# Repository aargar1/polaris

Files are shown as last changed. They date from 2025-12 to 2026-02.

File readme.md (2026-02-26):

# Polaris
Polaris is a feature-rich development board built around the Lattice iCE40 FPGA, designed for experimentation and small FPGA-based projects. The board provides a practical set of peripherals for graphics, storage, and USB-based interaction, all in a compact and approachable design. I designed it to implement a custom 32-bit microcontroller.



## Features

- Lattice iCE40 FPGA
- VGA output with audio support
- SD card interface
- 2× USB Type-A ports
- User-controllable LED
- GPIO and SPI headers

## Tooling

Polaris is plug-and-play compatable with the `yosys` toolchain. The [iCEStudio](https://icestudio.io/) development enviornment provides a great ecosystem for development on Polaris and iCE40-based boards in general.

## Acknowlegments

Thanks to the open-source FPGA and KiCad communities, whose tools and documentation made this project possible.

## BOM (Hack Club Blueprint)
| Comment | Designator | Footprint | LCSC Part # | Direct Link |
| --- | --- | --- | --- | --- |
| 2150 | R11,R3,R7 | 0603 | C2960889 | [https://www.lcsc.com/product-detail/C2960889.html](https://www.lcsc.com/product-detail/C2960889.html) |
| 2.7nF | C15,C16 | 0603 | C1609 | [https://www.lcsc.com/product-detail/C1609.html](https://www.lcsc.com/product-detail/C1609.html) |
| Bus | J4 | 2x14 2.54mm | C725886 | [https://www.lcsc.com/product-detail/C725886.html](https://www.lcsc.com/product-detail/C725886.html) |
| VGA | J1 | ICD15S13E4GV00LF | C3121412 | [https://www.lcsc.com/product-detail/C3121412.html](https://www.lcsc.com/product-detail/C3121412.html) |
| 74CBTLV3126PW,118 | U2 | TSSOP-14 | C478017 | [https://www.lcsc.com/product-detail/C478017.html](https://www.lcsc.com/product-detail/C478017.html) |
| 47k | R17,R19–R24,R27,R30,R31 | 0603 | C25819 | [https://www.lcsc.com/product-detail/C25819.html](https://www.lcsc.com/product-detail/C25819.html) |
| WM8524CGEDT | U3 | TSSOP-16 | C146242 | [https://www.lcsc.com/product-detail/C146242.html](https://www.lcsc.com/product-detail/C146242.html) |
| 1Ω | R28,R29 | 0603 | C22936 | [https://www.lcsc.com/product-detail/C22936.html](https://www.lcsc.com/product-detail/C22936.html) |
| NRS4018T2R2MDGJ | L1 | SRN4018 | C92959 | [https://www.lcsc.com/product-detail/C92959.html](https://www.lcsc.com/product-detail/C92959.html) |
| W25Q16JVSNIQ | U4 | SOIC-8 | C115407 | [https://www.lcsc.com/product-detail/C115407.html](https://www.lcsc.com/product-detail/C115407.html) |
| 330Ω | R35,R36,R37 | 0603 | C23138 | [https://www.lcsc.com/product-detail/C23138.html](https://www.lcsc.com/product-detail/C23138.html) |
| TLV62568DBVR | U7 | SOT-23-5 | C163219 | [https://www.lcsc.com/product-detail/C163219.html](https://www.lcsc.com/product-detail/C163219.html) |
| 100nF | C1,C2,C3,C4,C5,C10,C14,C27,C30  | 0603 | C14663 | [https://www.lcsc.com/product-detail/C14663.html](https://www.lcsc.com/product-detail/C14663.html) |
| SW_Push | SW1 | 6mm | C455112 | [https://www.lcsc.com/product-detail/C455112.html](https://www.lcsc.com/product-detail/C455112.html) |
| 1.5k | R32,R33 | 0603 | C22843 | [https://www.lcsc.com/product-detail/C22843.html](https://www.lcsc.com/product-detail/C22843.html) |
| USB_A | J5,J6 | XKB U231-091N | C2880618 | [https://www.lcsc.com/product-detail/C2880618.html](https://www.lcsc.com/product-detail/C2880618.html) |
| 4.7uF | C6,C7,C8,C9,C17,C18,C19 | 0603 | C19666 | [https://www.lcsc.com/product-detail/C19666.html](https://www.lcsc.com/product-detail/C19666.html) |
| ICE40UP5K-SG48I | U1 | QFN-48 | C2678152 | [https://www.lcsc.com/product-detail/C2678152.html](https://www.lcsc.com/product-detail/C2678152.html) |
| Flashenable | JP1 | 1x02 2.54mm | C5360898 | [https://www.lcsc.com/product-detail/C5360898.html](https://www.lcsc.com/product-detail/C5360898.html) |
| LED_BGKR | D1 | 5mm RGB | C7117555 | [https://www.lcsc.com/product-detail/C7117555.html](https://www.lcsc.com/product-detail/C7117555.html) |
| 820Ω | R13,R14 | 0603 | C23253 | [https://www.lcsc.com/product-detail/C23253.html](https://www.lcsc.com/product-detail/C23253.html) |
| 10uF | C23,C24,C25,C26,C28,C29,C31,C32 | 0805 | C15850 | [https://www.lcsc.com/product-detail/C15850.html](https://www.lcsc.com/product-detail/C15850.html) |
| 560Ω | R25,R26 | 0603 | C23204 | [https://www.lcsc.com/product-detail/C23204.html](https://www.lcsc.com/product-detail/C23204.html) |
| 536Ω | R1,R5,R9 | 0603 | C23201 | [https://www.lcsc.com/product-detail/C23201.html](https://www.lcsc.com/product-detail/C23201.html) |
| SX5M25.000M20F30TNN | X1 | 25MHz Osc | C2901535 | [https://www.lcsc.com/product-detail/C2901535.html](https://www.lcsc.com/product-detail/C2901535.html) |
| MIC5504-3.3YM5 | U8 | SOT-23-5 | C41348078 | [https://www.lcsc.com/product-detail/C41348078.html](https://www.lcsc.com/product-detail/C41348078.html) |
| Prog | J2 | 1x08 2.54mm | C5156616 | [https://www.lcsc.com/product-detail/C5156616.html](https://www.lcsc.com/product-detail/C5156616.html) |
| FerriteBead_Small | FB1,FB2 | 0603 | C1027 | [https://www.lcsc.com/product-detail/C1027.html](https://www.lcsc.com/product-detail/C1027.html) |
| 4300Ω | R12,R4,R8 | 0603 | C23159 | [https://www.lcsc.com/product-detail/C23159.html](https://www.lcsc.com/product-detail/C23159.html) |
| 1uF | C12,C13 | 0603 | C15849 | [https://www.lcsc.com/product-detail/C15849.html](https://www.lcsc.com/product-detail/C15849.html) |
| 2.2uF | C11 | 0603 | C23630 | [https://www.lcsc.com/product-detail/C23630.html](https://www.lcsc.com/product-detail/C23630.html) |
| 10k | R15,R16,R18,R34 | 0603 | C25804 | [https://www.lcsc.com/product-detail/C25804.html](https://www.lcsc.com/product-detail/C25804.html) |
| 1070Ω | R10,R2,R6 | 0603 | C177957 | [https://www.lcsc.com/product-detail/C177957.html](https://www.lcsc.com/product-detail/C177957.html) |
| Barrel_Jack | J7 | PJ-063AH | C22434582 | [https://www.lcsc.com/product-detail/C22434582.html](https://www.lcsc.com/product-detail/C22434582.html) |
| SD_Card | J3 | 693063010911 | C341097 | [https://www.lcsc.com/product-detail/C341097.html](https://www.lcsc.com/product-detail/C341097.html) |
| SN74AHC00PWR | U9 | TSSOP-14 | C8143 | [https://www.lcsc.com/product-detail/C8143.html](https://www.lcsc.com/product-detail/C8143.html) |

## License
This project is licensed under the CERN Open Hardware Licence Version 2. If you would like to use Assemblage for a patently non-commercial or educational application, but cannot do so under this license, please contact me via an issue; I would be happy to work something out.

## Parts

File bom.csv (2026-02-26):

Comment | Designator | Footprint | LCSC Part #
2150 | R11,R3,R7 | 0603 | C2960889
2.7nF | C15,C16 | 0603 | C1609
Bus | J4 | PinHeader_2x14_P2.54mm_Vertical | C725886
VGA | J1 | ICD15S13E4GV00LF | C3121412
74CBTLV3126PW | 118 | U2 | TSSOP-14_4.4x5mm_P0.65mm | C478017
47k | R17,R19,R20,R21,R22,R23,R24,R27,R30,R31 | 0603 | C25819
WM8524CGEDT | U3 | TSSOP-16_4.4x5mm_P0.65mm | C146242
1 | R28,R29 | 0603 | C22936
NRS4018T2R2MDGJ | L1 | L_Bourns-SRN4018 | C92959
W25Q16JVSNIQ | U4 | SOIC-8_3.9x4.9mm_P1.27mm | C115407
330 | R35,R36,R37 | 0603 | C23138
TLV62568DBVR | U7 | SOT-23-5 | C163219
100nF | C1,C10,C14,C2,C27,C3,C30,C4,C5 | 0603 | C14663
SW_Push | SW1 | SW_PUSH_6mm | C455112
1.5k | R32,R33 | 0603 | C22843
USB_A | J5,J6 | USB_A_Receptacle_XKB_U231-091N-4BLRA00-S | C2880618
4.7uF | C17,C18,C19,C6,C7,C8,C9 | 0603 | C19666
ICE40UP5K-SG48I | U1 | QFN-48-1EP_7x7mm_P0.5mm_EP5.3x5.3mm | C2678152
Flashenable | JP1 | PinHeader_1x02_P2.54mm_Vertical | C5360898
LED_BGKR | D1 | LED_D5.0mm-4_RGB_Wide_Pins | C7117555
820 | R13,R14 | 0603 | C23253
10uF | C23,C24,C25,C26,C28,C29,C31,C32 | 0805 | C15850
560 | R25,R26 | 0603 | C23204
536 | R1,R5,R9 | 0603 | C23201
SX5M25.000M20F30TNN | X1 | Oscillator_SMD_SeikoEpson_SG8002LB-4Pin_5.0x3.2mm | C2901535
MIC5504-3.3YM5 | U8 | SOT-23-5 | C41348078
Prog | J2 | PinHeader_1x08_P2.54mm_Vertical | C5156616
FerriteBead_Small | FB1,FB2 | 0603 | C1027
4300 | R12,R4,R8 | 0603 | C23159
1u | C12,C13 | 0603 | C15849
2.2uF | C11 | 0603 | C23630
10k | R15,R16,R18,R34 | 0603 | C25804
1070 | R10,R2,R6 | 0603 | C177957
Barrel_Jack | J7 | BarrelJack_CUI_PJ-063AH_Horizontal | C22434582
SD_Card | J3 | 693063010911 | C341097
SN74AHC00PWR | U9 | TSSOP-14_4.4x5mm_P0.65mm | C8143

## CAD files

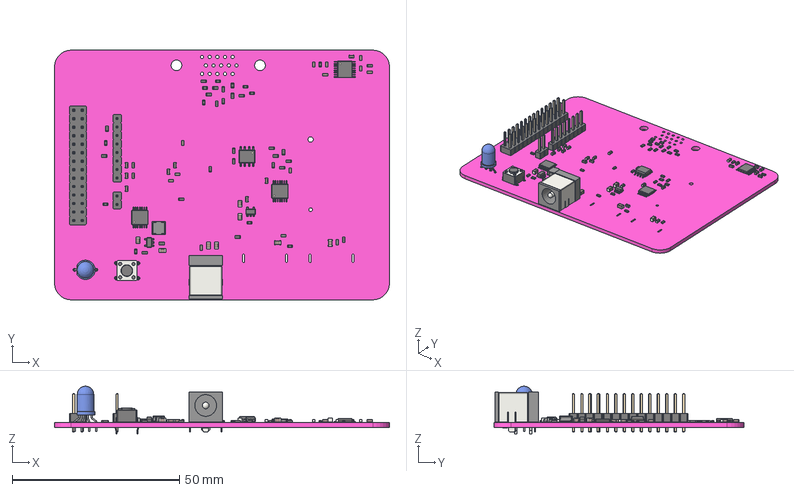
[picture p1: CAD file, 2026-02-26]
Polaris.step
100.2 x 74.8 x 14.3 mm
R_0603_1608Metric x 37
C_0805_2012Metric x 8
TSSOP-14_4.4x5mm_P0.65mm x 2
C_0603_1608Metric x 21
SOIC-8_3.9x4.9mm_P1.27mm
L_0603_1608Metric x 2
PinHeader_1x08_P2.54mm_Vertical
SOT-23-5 x 2
L_Bourns-SRN4018
PinHeader_2x14_P2.54mm_Vertical
PinHeader_1x02_P2.54mm_Vertical
BarrelJack_CUI_PJ-063AH_Horizontal
SW_PUSH_6mm
LED_D5.0mm-4_RGB_Wide_Pins
TSSOP-16_4.4x5mm_P0.65mm
Polaris_PCB

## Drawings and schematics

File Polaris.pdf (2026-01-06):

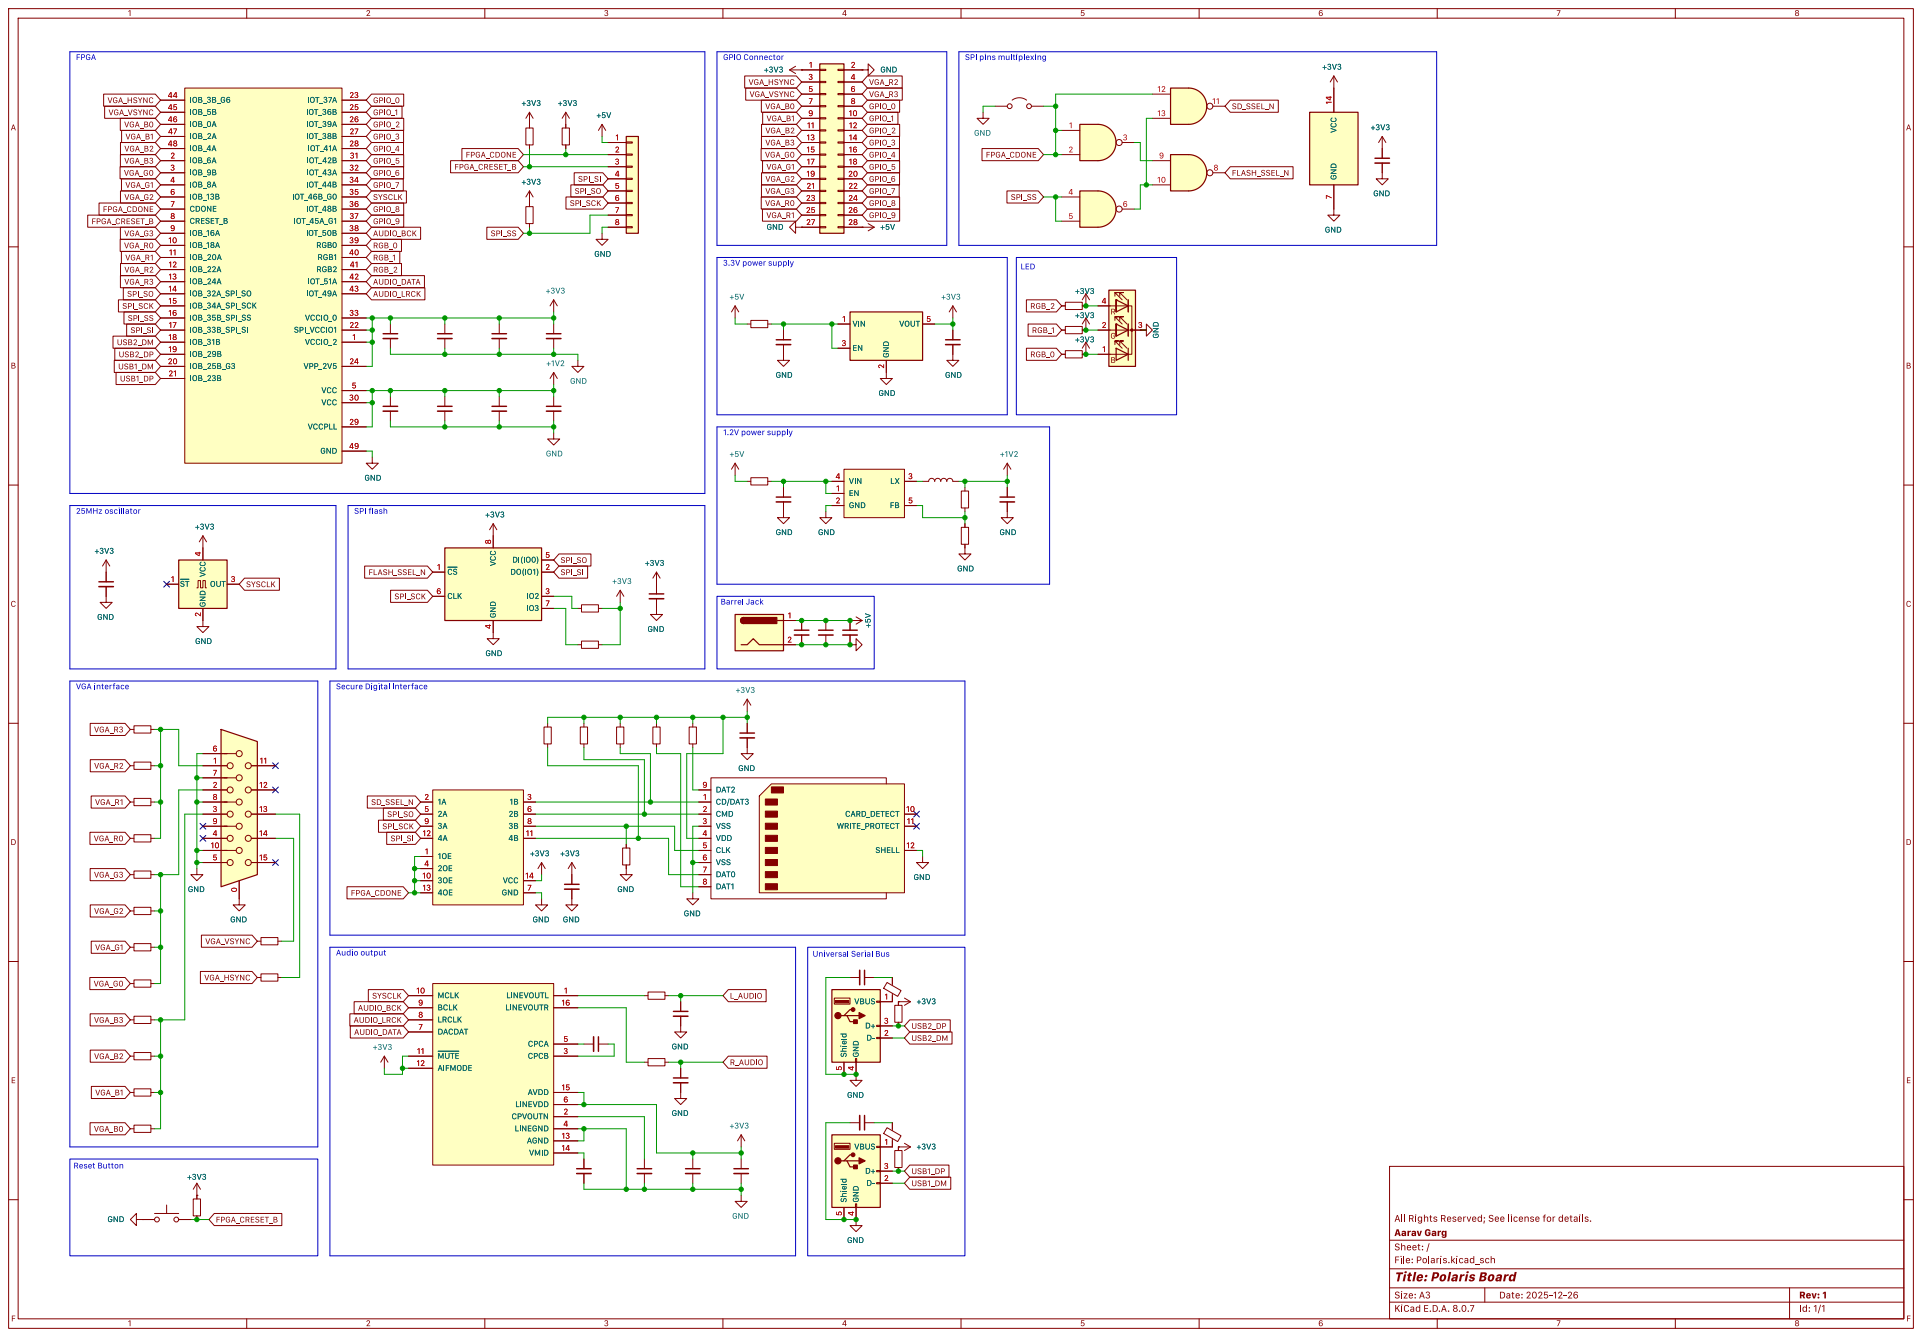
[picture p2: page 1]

File: Polaris.kicad_sch Sheet: / Aarav Garg All Rights Reserved; See license for details.

Id: 1/1 Title: Polaris Board

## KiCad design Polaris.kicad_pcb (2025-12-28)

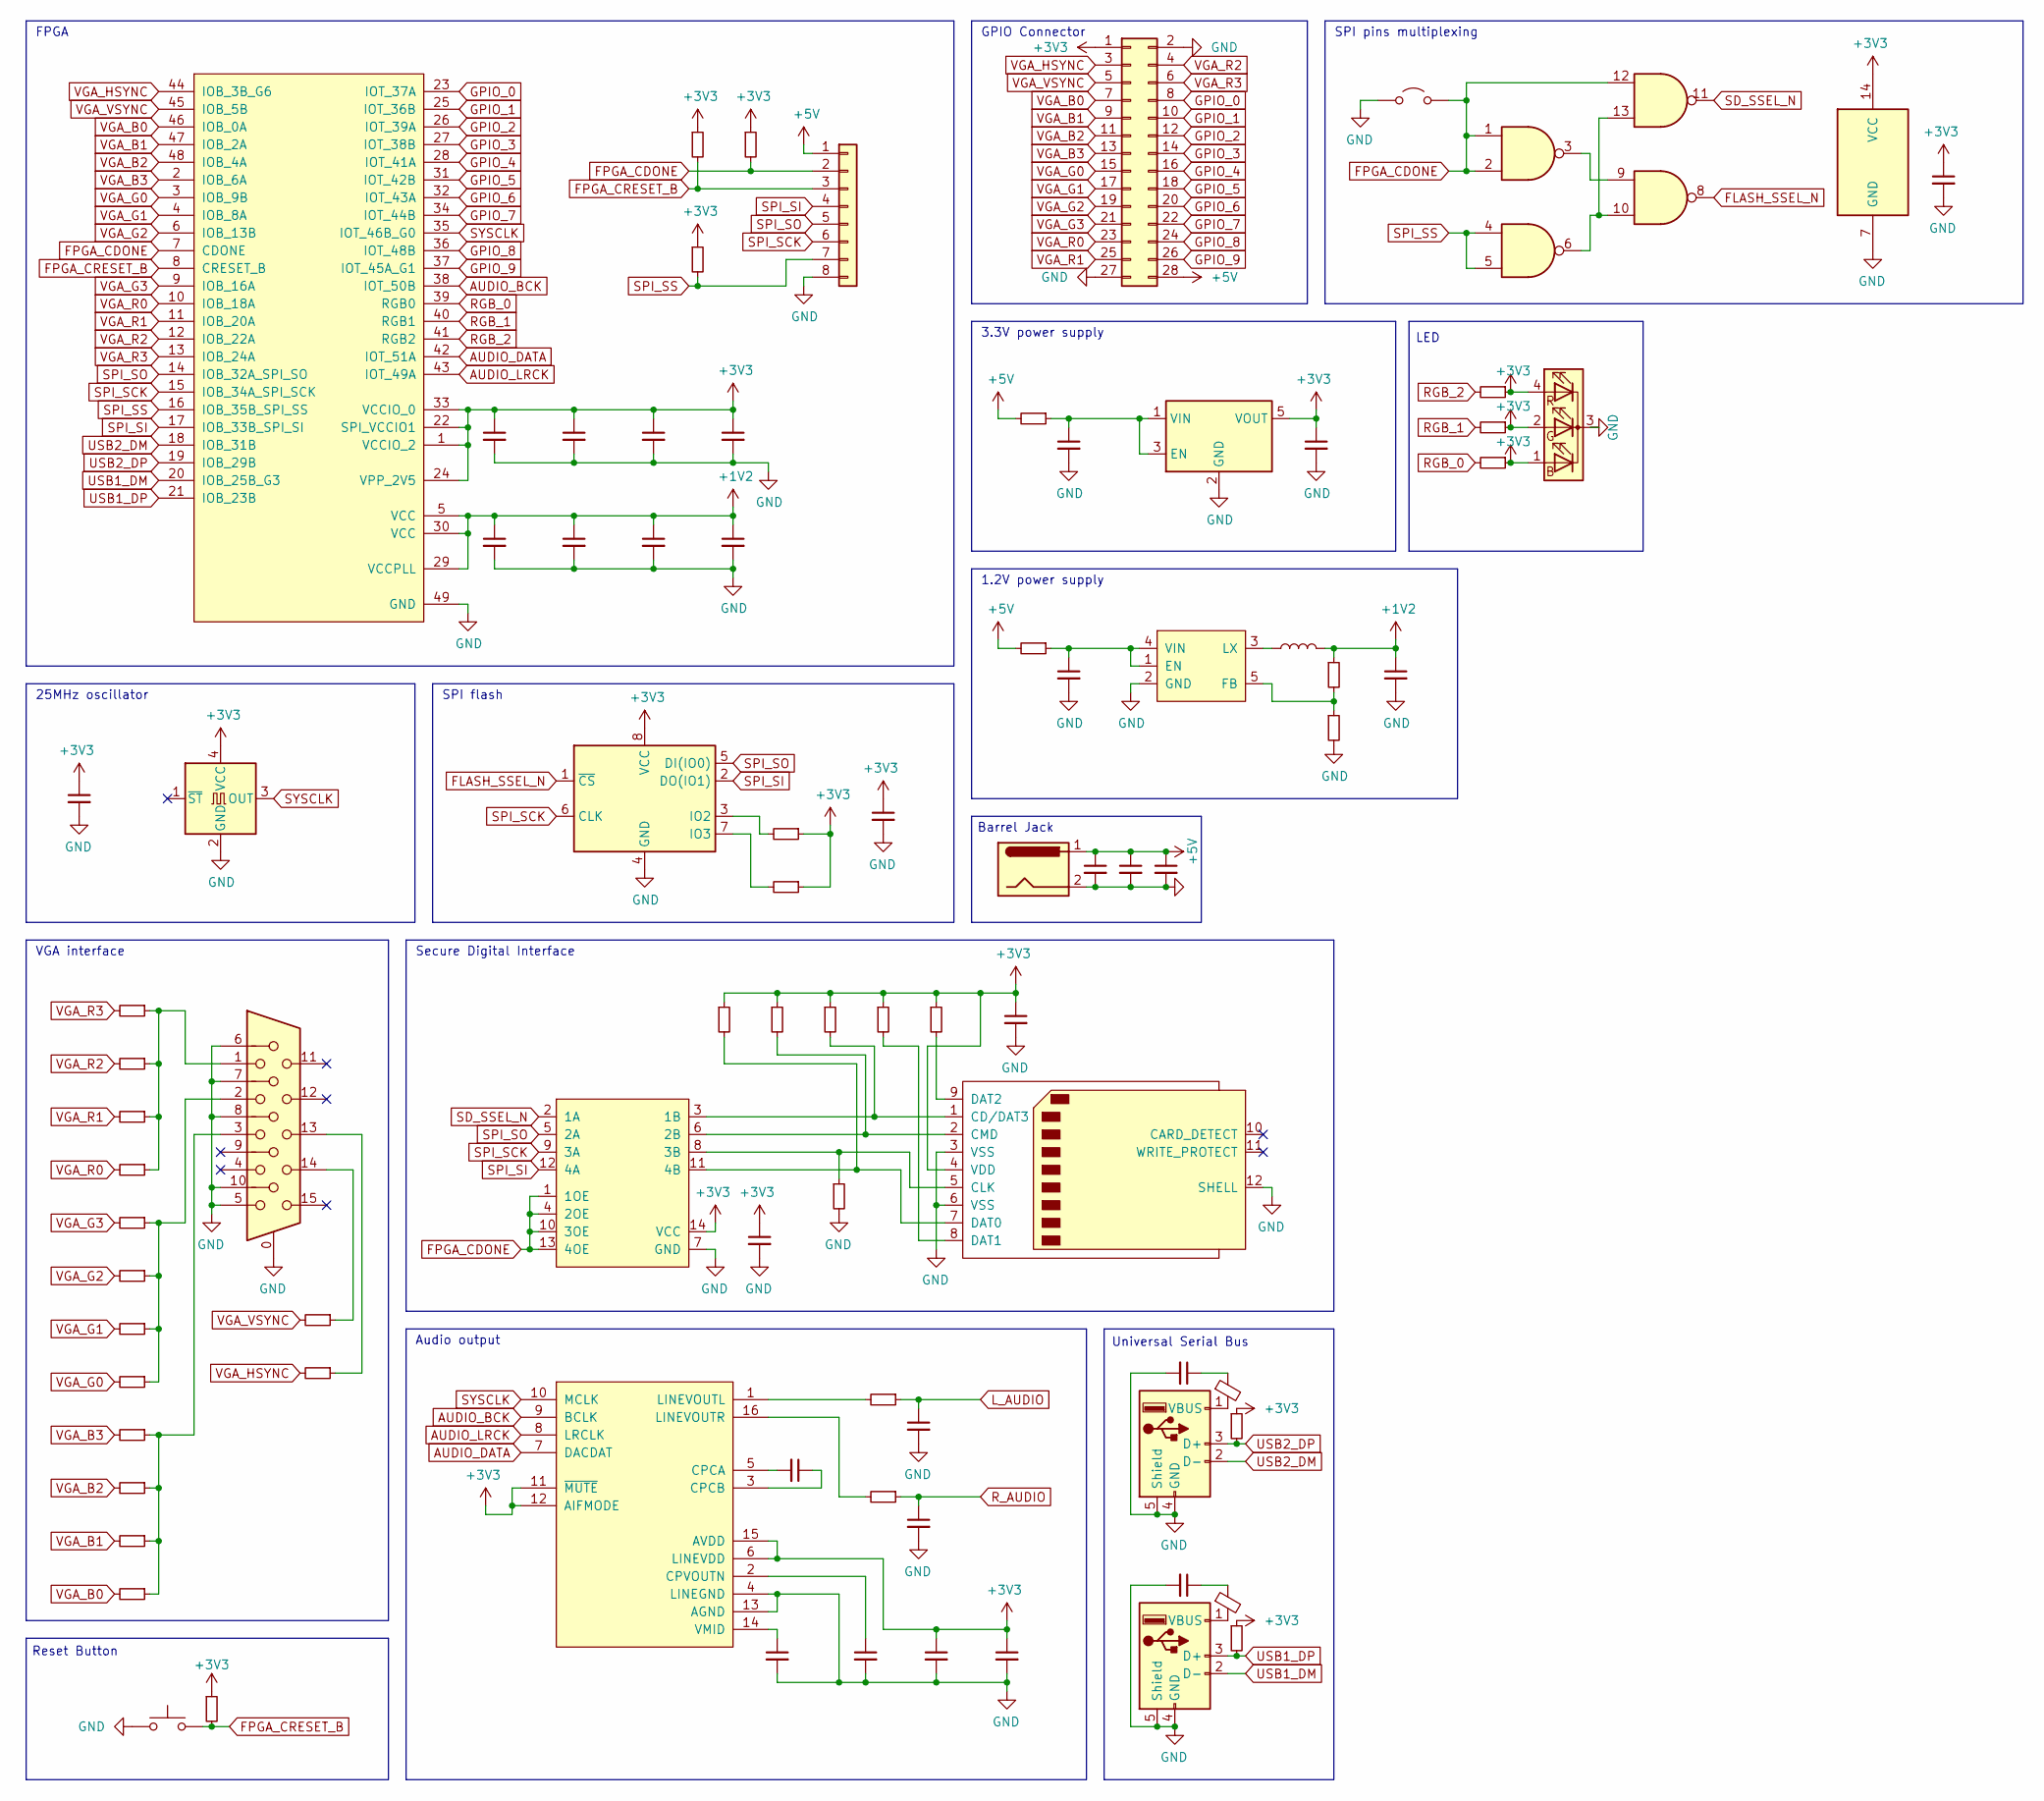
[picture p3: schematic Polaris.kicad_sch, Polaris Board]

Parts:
C1, C2, C3, C4, C5, C10, C14, C27, C30: 100nF; C_0603_1608Metric
C6, C7, C8, C9, C17, C18, C19: 4.7uF; C_0603_1608Metric
C11: 2.2uF; C_0603_1608Metric
C12: 1u; C_0603_1608Metric
C13: 1uF; C_0603_1608Metric
C15, C16: 2.7nF; C_0603_1608Metric
C23, C24, C25, C26, C28, C29, C31, C32: 10uF; C_0805_2012Metric
D1: LED_BGKR; LED_D5.0mm-4_RGB_Wide_Pins
FB1, FB2: FerriteBead_Small; L_0603_1608Metric
J1: VGA; ICD15S13E4GV00LF
J2: Prog; PinHeader_1x08_P2.54mm_Vertical
J3: SD_Card; 693063010911
J4: Bus; PinHeader_2x14_P2.54mm_Vertical
J5, J6: USB_A; USB_A_Receptacle_XKB_U231-091N-4BLRA00-S
J7: Barrel_Jack; BarrelJack_CUI_PJ-063AH_Horizontal
JP1: Flash enable; PinHeader_1x02_P2.54mm_Vertical
L1: NRS4018T2R2MDGJ; L_Bourns-SRN4018
R1, R5, R9: 536; R_0603_1608Metric
R2, R6, R10: 1070; R_0603_1608Metric
R3, R7, R11: 2150; R_0603_1608Metric
R4, R8, R12: 4300; R_0603_1608Metric
R13, R14: 820; R_0603_1608Metric
R15, R16, R18, R34: 10k; R_0603_1608Metric
R17, R19, R20, R21, R22, R23, R24, R27, R30, R31: 47k; R_0603_1608Metric
R25, R26: 560; R_0603_1608Metric
R28, R29: 1; R_0603_1608Metric
R32, R33: 1.5k; R_0603_1608Metric
R35, R36, R37: 330; R_0603_1608Metric
SW1: SW_Push; SW_PUSH_6mm
U1: ICE40UP5K-SG48I; QFN-48-1EP_7x7mm_P0.5mm_EP5.3x5.3mm
U2: 74CBTLV3126PW,118; TSSOP-14_4.4x5mm_P0.65mm
U3: WM8524CGEDT; TSSOP-16_4.4x5mm_P0.65mm
U4: W25Q16JVSNIQ; SOIC-8_3.9x4.9mm_P1.27mm
U7: TLV62568DBVR; SOT-23-5
U8: MIC5504-3.3YM5; SOT-23-5
U9: SN74AHC00PWR; TSSOP-14_4.4x5mm_P0.65mm
X1: SX5M25.000M20F30TNN; Oscillator_SMD_SeikoEpson_SG8002LB-4Pin_5.0x3.2mm

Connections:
+1V2: C3.1, C5.1, C7.1, C9.1, C26.1, L1.2, R30.1, U1.5 (VCC), U1.29 (VCCPLL), U1.30 (VCC)
+3V3: C1.1, C2.1, C4.1, C6.1, C8.1, C10.1, C14.1, C17.1, C18.1, C19.1, C25.1, C27.1, D1.1 (BA), D1.2 (GA), D1.4 (RA), J3.4 (VDD), J4.1, R15.1, R16.1, R17.1, R18.1, R19.1, R20.1, R21.1, R22.1, R24.1, R27.1, R32.1, R33.1, R34.1, R35.1, R36.1, R37.1, U1.1 (VCCIO_2), U1.22 (SPI_VCCIO1), U1.24 (VPP_2V5), U1.33 (VCCIO_0), U2.14 (VCC), U3.6 (LINEVDD), U3.11 (~MUTE), U3.12 (AIFMODE), U3.15 (AVDD), U4.8 (VCC), U8.5 (VOUT), U9.14 (VCC), X1.4 (VCC)
+5V: C30.1, C31.1, C32.1, J2.1, J4.28, J7.1, R28.2, R29.2
AUDIO_BCK: U1.38 (IOT_50B), U3.9 (BCLK)
AUDIO_DATA: U1.42 (IOT_51A), U3.7 (DACDAT)
AUDIO_LRCK: U1.43 (IOT_49A), U3.8 (LRCLK)
FLASH_SSEL_N: U4.1 (~CS), U9.8
FPGA_CDONE: J2.2, JP1.2 (B), R18.2, U1.7 (CDONE), U2.1 (1OE), U2.4 (2OE), U2.10 (3OE), U2.13 (4OE), U9.1, U9.2, U9.12
FPGA_CRESET_B: J2.3, R15.2, R34.2, SW1.2, U1.8 (CRESET_B)
GND: C1.2, C2.2, C3.2, C4.2, C5.2, C6.2, C7.2, C8.2, C9.2, C10.2, C11.2, C13.2, C14.2, C15.2, C16.2, C17.2, C18.2, C19.2, C23.2, C24.2, C25.2, C26.2, C27.2, C28.2, C29.2, C30.2, C31.2, C32.2, D1.3 (K), J1.0, J1.5, J1.6, J1.7, J1.8, J1.10, J2.8, J3.3 (VSS), J3.6 (VSS), J3.12 (SHELL), J4.2, J4.27, J5.4 (GND), J5.5 (Shield), J6.4 (GND), J6.5 (Shield), J7.2, JP1.1 (A), R23.2, R31.2, SW1.1, U1.49 (GND), U2.7 (GND), U3.4 (LINEGND), U3.13 (AGND), U4.4 (GND), U7.2 (GND), U8.2 (GND), U9.7 (GND), X1.2 (GND)
GPIO_0: J4.8, U1.23 (IOT_37A)
GPIO_1: J4.10, U1.25 (IOT_36B)
GPIO_2: J4.12, U1.26 (IOT_39A)
GPIO_3: J4.14, U1.27 (IOT_38B)
GPIO_4: J4.16, U1.28 (IOT_41A)
GPIO_5: J4.18, U1.31 (IOT_42B)
GPIO_6: J4.20, U1.32 (IOT_43A)
GPIO_7: J4.22, U1.34 (IOT_44B)
GPIO_8: J4.24, U1.36 (IOT_48B)
GPIO_9: J4.26, U1.37 (IOT_45A_G1)
L_AUDIO: C15.1, R25.1
unnamed: C28.1, FB1.1
unnamed: C29.1, FB2.1
unnamed: J1.1, R1.1, R2.1, R3.1, R4.1
unnamed: J1.2, R5.1, R6.1, R7.1, R8.1
unnamed: J1.3, R9.1, R10.1, R11.1, R12.1
unnamed: J1.13, R14.1
unnamed: J1.14, R13.1
unnamed: J3.1 (CD/DAT3), R22.2, U2.3 (1B)
unnamed: J3.5 (CLK), R23.1, U2.8 (3B)
unnamed: J3.2 (CMD), R19.2, U2.6 (2B)
unnamed: J3.7 (DAT0), R17.2, U2.11 (4B)
unnamed: J3.8 (DAT1), R24.2
unnamed: J3.9 (DAT2), R27.2
unnamed: FB1.2, J5.1 (VBUS)
unnamed: FB2.2, J6.1 (VBUS)
unnamed: C12.2, U3.5 (CPCA)
unnamed: C12.1, U3.3 (CPCB)
unnamed: C13.1, U3.2 (CPVOUTN)
unnamed: R25.2, U3.1 (LINEVOUTL)
unnamed: R26.2, U3.16 (LINEVOUTR)
unnamed: C11.1, U3.14 (VMID)
unnamed: R20.2, U4.3 (IO2)
unnamed: R21.2, U4.7 (IO3)
unnamed: C24.1, R29.1, U7.1 (EN), U7.4 (VIN)
unnamed: R30.2, R31.1, U7.5 (FB)
unnamed: L1.1, U7.3 (LX)
unnamed: C23.1, R28.1, U8.1 (VIN), U8.3 (EN)
unnamed: U9.3, U9.9
unnamed: U9.6, U9.10, U9.13
RGB_0: R37.2, U1.39 (RGB0)
RGB_1: R36.2, U1.40 (RGB1)
RGB_2: R35.2, U1.41 (RGB2)
R_AUDIO: C16.1, R26.1
SD_SSEL_N: U2.2 (1A), U9.11
SPI_SCK: J2.6, U1.15 (IOB_34A_SPI_SCK), U2.9 (3A), U4.6 (CLK)
SPI_SI: J2.4, U1.17 (IOB_33B_SPI_SI), U2.12 (4A), U4.2 (DO(IO1))
SPI_SO: J2.5, U1.14 (IOB_32A_SPI_SO), U2.5 (2A), U4.5 (DI(IO0))
SPI_SS: J2.7, R16.2, U1.16 (IOB_35B_SPI_SS), U9.4, U9.5
SYSCLK: U1.35 (IOT_46B_G0), U3.10 (MCLK), X1.3 (OUT)
USB1_DM: J6.2 (D-), U1.20 (IOB_25B_G3)
USB1_DP: J6.3 (D+), R33.2, U1.21 (IOB_23B)
USB2_DM: J5.2 (D-), U1.18 (IOB_31B)
USB2_DP: J5.3 (D+), R32.2, U1.19 (IOB_29B)
VGA_B0: J4.7, R12.2, U1.46 (IOB_0A)
VGA_B1: J4.9, R11.2, U1.47 (IOB_2A)
VGA_B2: J4.11, R10.2, U1.48 (IOB_4A)
VGA_B3: J4.13, R9.2, U1.2 (IOB_6A)
VGA_G0: J4.15, R8.2, U1.3 (IOB_9B)
VGA_G1: J4.17, R7.2, U1.4 (IOB_8A)
VGA_G2: J4.19, R6.2, U1.6 (IOB_13B)
VGA_G3: J4.21, R5.2, U1.9 (IOB_16A)
VGA_HSYNC: J4.3, R14.2, U1.44 (IOB_3B_G6)
VGA_R0: J4.23, R4.2, U1.10 (IOB_18A)
VGA_R1: J4.25, R3.2, U1.11 (IOB_20A)
VGA_R2: J4.4, R2.2, U1.12 (IOB_22A)
VGA_R3: J4.6, R1.2, U1.13 (IOB_24A)
VGA_VSYNC: J4.5, R13.2, U1.45 (IOB_5B)

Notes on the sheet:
25MHz oscillator
VGA interface
SPI pins multiplexing
Secure Digital Interface
Audio output
Reset Button
Universal Serial Bus
1.2V power supply
LED
FPGA
SPI flash
3.3V power supply
GPIO Connector
Barrel Jack

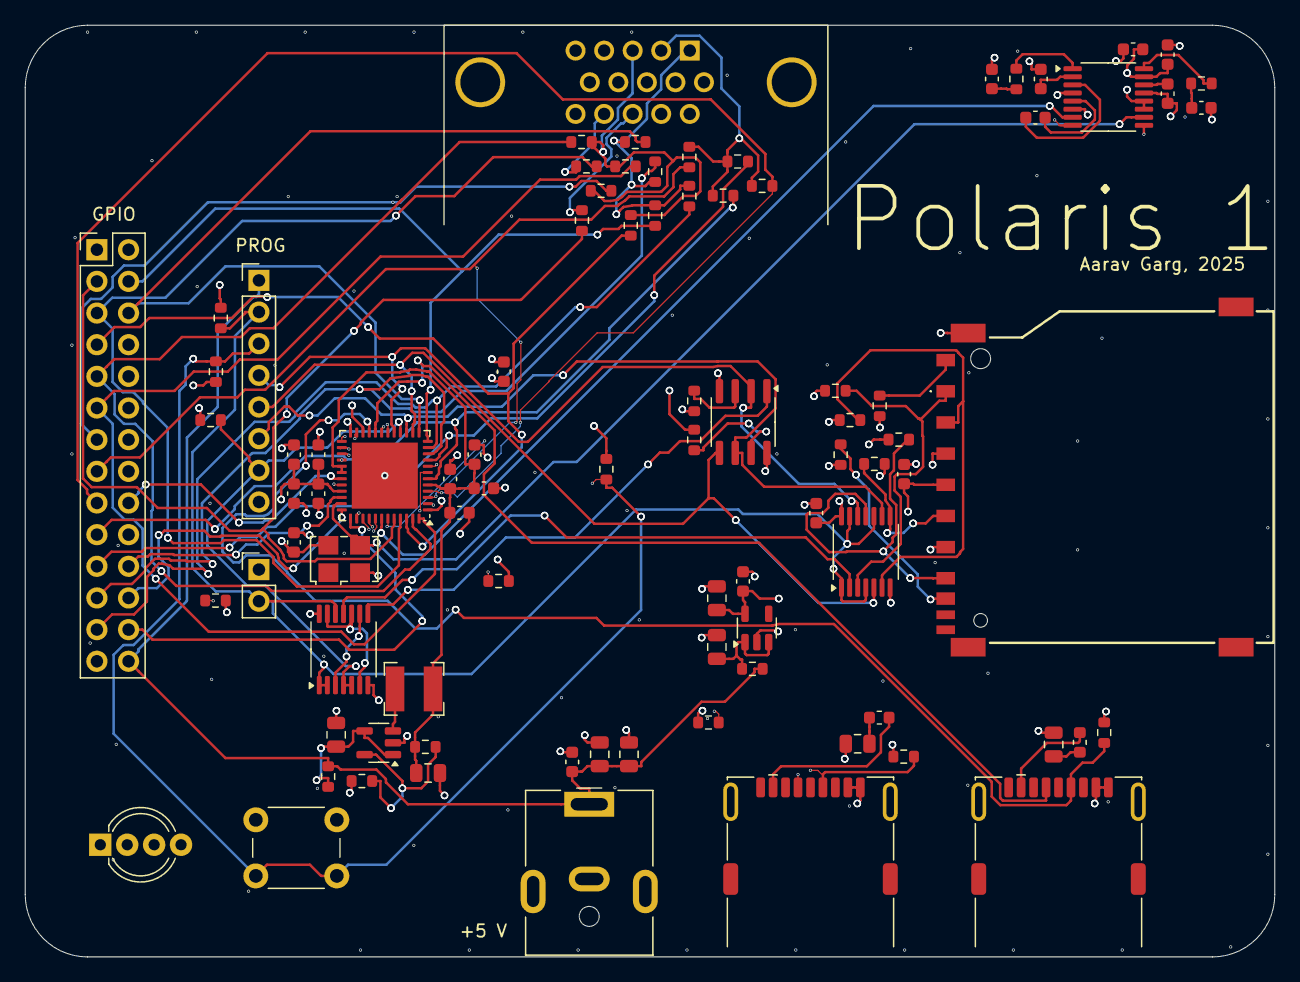
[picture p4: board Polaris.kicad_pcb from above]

Board: 6 copper layers, 100.2 x 74.8 mm, 87 parts (0 on the bottom side), 78 nets.

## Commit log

2026-01-04 Add initial README for Polaris development board
2026-02-26 Add BOM with components and specifications
    Added bill of materials with component details.
    [bom.csv]
